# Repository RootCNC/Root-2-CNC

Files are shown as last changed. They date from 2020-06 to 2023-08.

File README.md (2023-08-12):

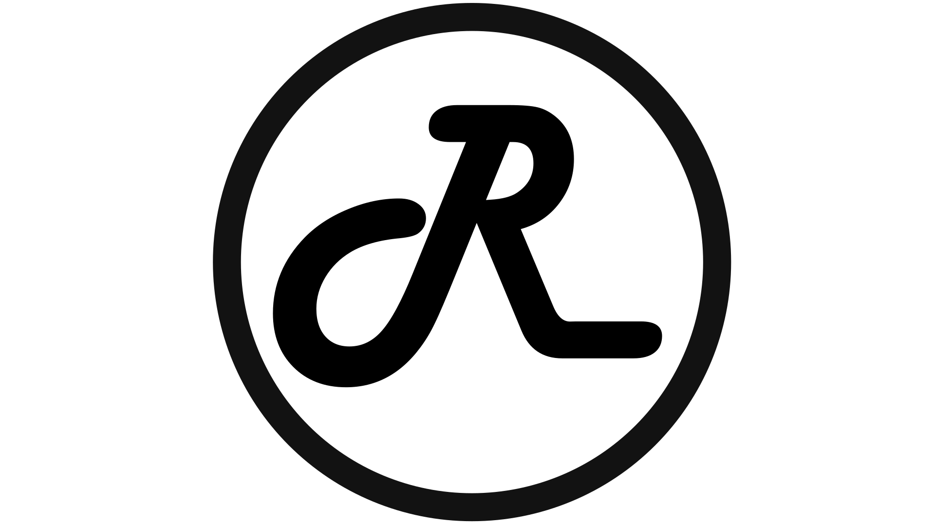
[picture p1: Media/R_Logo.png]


# Root 2 
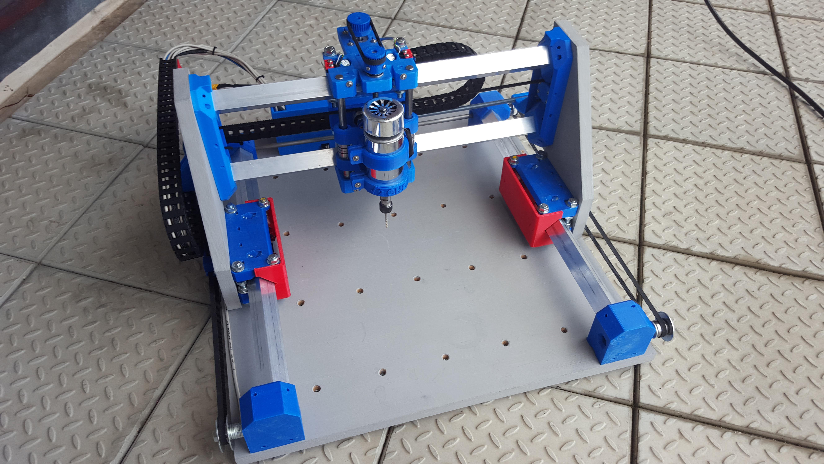
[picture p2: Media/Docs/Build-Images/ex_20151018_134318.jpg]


I started this project to enable me to do another project which required sheet wood to be machined, (another 3D printer which I have been wanting to do for a while). without the large cost of out sourcing the tasks to a company. So I created this CNC named Root 2 to open up a endless amount of possibilities.
Why make it open source? Since getting involved with 3D printing and the whole open source community, it has taught me many things and open doors which might not have been open without the added experience the community has given me. So I thought what a great way to put something small back into very thing what got me hooked in the magical world of CNC machine - the open source community.
If you make one or remix it, I would love to see it! post some photos and show it off! =]
Goals

Create a expandable CNC machine capable to machine aluminiumUse minimal different 3D printed partsCustomization (Make it Bigger)CheapSimpleUse parts commonly used in DIY 3D printerEasily sourced parts

# Goals
 1. Create a expandable CNC machine 
 2. capable to machine aluminium
 3. Use minimal different 3D printed parts 
 4. Customization (Make it Bigger)
 5. Cheap Simple 
 6. Use parts commonly used in DIY 3D printer
 7. Easily sourced parts
 
# Spec
Working Area = 331x305x120mm (X,Y,Z) - If you want a bigger machine, just buy longer box section!

# Animated Assembly 
[Here](https://www.youtube.com/watch?v=ruxc2kX1mUY&list=PL5hghy18PulU0-F_gzihovUwgWx6q6PMu&ab_channel=Sailorpete)

# BOM
Can be found [HERE](https://github.com/RootCNC/Root-2-CNC/blob/master/Docs/BOM.md)

# Videos
Youtube Videos can be found  [Here](https://www.youtube.com/sailorpete12)

Animated Assembly [Here](https://www.youtube.com/watch?v=ruxc2kX1mUY&list=PL5hghy18PulU0-F_gzihovUwgWx6q6PMu&ab_channel=Sailorpete)

## Dibond sheet
(http://www.youtube.com/watch?v=g2_bGaUY4f0 "")
## Hard Oak Sign making
(http://www.youtube.com/watch?v=TYWPhoFjMDA "")
## Aluminum
(http://www.youtube.com/watch?v=S1ygUxeEE4I "")
## Root 2 Sign
(http://www.youtube.com/watch?v=rYxTZAJLHNU "")
## Acrylic
(http://www.youtube.com/watch?v=3Kr6_sbjg4U "")
## MDF
(http://www.youtube.com/watch?v=sJx-P0i7J8o "")
## Pen Testing
(http://www.youtube.com/watch?v=YvVPL7FzFdo "")
## Movement Testing
(http://www.youtube.com/watch?v=Uq5E_fRXPA0 "")

## License

This project is licensed under the Creative Commons 4.0 license with 
Attribution-NonCommerial-ShareAlike see `LICENSE.txt` for details

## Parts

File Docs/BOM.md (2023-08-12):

---
title: Root 2 Bill of Materials
description: Root 2 Bill of Materials
published: true
date: 2022-06-28T21:37:30.411Z
tags: root 2, r2, BOM
editor: markdown
dateCreated: 2022-05-24T19:30:47.756Z
---

# Plastic Parts
|Qty | Item  |
|--|--|
|2x |Root 2 CNC - Y gantry assm-1 Y-Axis Belt Clamp GT2|
|4x |Root 2 CNC - Y gantry assm-1 Y Motion Bearing Mount|
|1x |Root 2 CNC - Y gantry assm-1 Y Drag Chain Carriage|
|1x |Root 2 CNC - Y gantry assm-1 X-Axis Carriage Y Drag Chain Mount|
|1x |Root 2 CNC - Y gantry assm-1 X-Axis Carriage Y Drag Chain Mount Idler|
|2x |Root 2 CNC - Y gantry assm-1 X-Axis Belt Clamp|
|2x |Root 2 CNC - Y gantry assm-1 X-Axis Box Bar Mount|
|2x |Root 2 CNC - Y gantry assm-1 Dirt Cover|
|1x |Root 2 CNC - X carriage-1 Z-Axis Motor Mount|
|1x |Root 2 CNC - X carriage-1 Z carriage-1 Spindle Upper Clamp|
|1x |Root 2 CNC - X carriage-1 Z carriage-1 Spindle Lower Clamp|
|1x |Root 2 CNC - X carriage-1 X-Axis Motor Mount|
|1x |Root 2 CNC - X carriage-1 X-Axis Carriage Drag Chain Mount Idler|
|2x |Root 2 CNC - X carriage-1 linear rail 90 bearing mount Y-Axis Carriage|
|1x |Root 2 CNC - X carriage-1 3M Pulley 32T 5mm|
|1x |Root 2 CNC - X carriage-1 3M Pulley 22T 8mm|
|1x |Root 2 CNC - Ramps controller-1 Ramps Case Lid|
|1x |Root 2 CNC - Ramps controller-1 Ramps Case Base|
|1x |Root 2 CNC - Base and Y axis assm-1 Y-Axis Bar Mount|
|1x |Root 2 CNC - Base and Y axis assm-1 Y-Axis Bar Mount Idler|
|1x |Root 2 CNC - Base and Y axis assm-1 Y-Axis Bar Mount Idler Mirror|
|1x |Root 2 CNC - Base and Y axis assm-1 Y-Axis Bar Mount Mirror|
|1x |Root 2 CNC - Base and Y axis assm-1 Y-Axis Motor Mount|
|1x |Root 2 CNC - Base and Y axis assm-1 Y-Axis Motor Mount Mirror|
|1x |Root 2 CNC - Base and Y axis assm-1 Y-Axis Drag Chain|
|1x |Root 2 CNC - Base and Y axis assm-1 3M Pulley 48T 8mm|
|1x |Root 2 CNC - Base and Y axis assm-1 3M Pulley 24T 5mm|
|4x |Root 2 CNC - Base and Y axis assm- Foot|
# Electronics
|Qty | Item  |
|--|--|
|1x| Arduino Mega + Ramps 1.4|
|3x| DRV8825 (Optional but preferred over the A4988)|
|3x| Nema 17 Stepper motors (Get the Highest torque possible)|
|1x| 60mm DC Fan|
|6x| Endstop micro switches (KW11 I drilled the whole to 3mm to screw then in to the plastic parts)|
|1x| DC Spindle (52mm Diameter - Get the highest wattage, you will be thank full later on)|
|1x| Diode This is needed if using the heatbed Mosfet on the ramps to control the spindle - google Mosfet switching inductive loads for more information|
|4| core AWG26 cable (use for motor wiring and endstops)|
# Fixings
|Qty | Item  |
|--|--|
|4x|M8 Penny washers|
|Lots|M8 Standard washers|
|lots|M8 Nuts|
|24x| M8 x 25mm Bolts|
|2x |M8 x 35-40mm Bolt|
|16x| M8 Tee Nuts|
|2x |M4 x 50mm Bolt|
|16x| M4 Nuts|
|16x| M4 Washer|
|16x| M4 x 40mm Bolt|
|Lots |M3 9mm Penny Washers|
|Lots |M3 Nuts|
|10x |M3 x 10mm|
|lots |M3 x 16,20,25,30,40 mm Lengths (good to have a selection on hand)
# Bearings
|Qty | Item  |
|--|--|
|36x| 608 Bearings|
|4x| LM10UU|
# Metal Work
|Qty | Item  |
|--|--|
|2x|Aluminum Box section (X-Axis) 25x25x496x3mm (W,D,L,T)|
|2x|Aluminum Box section (Y-Axis) 25x25x496x3mm (W,D,L,T)|
|1x|M8 Smooth Rod 580mm|
|8x|M8 Threaded Rod 85 mm|
|1x|M8 Threaded Rod 500 mm|
|2x|M8 Threaded Rod 200 mm|
|1x|M8 Threaded Rod 230 mm|
|2x|M8 Threaded Rod 100 mm|
|2x|M10 Smooth Rod 185 mm
# Motion
|Qty | Item  |
|--|--|
||GT2 Belt (Length depending on size of the of the machine)|
|2x|GT2 36T Pulley 8mm Bore|
|1x|3M-210T-06 Belt|
|1x|3M-264T-06 HTD|
|1x|GT2 16T Pulley 5mm Bore|
|2x|Drag Chain 20 x 10 mm 1m Length|
# Wood
|Qty | Item  |
|--|--|
|2x|Wood Side Panel|
|1x|Wood Base|

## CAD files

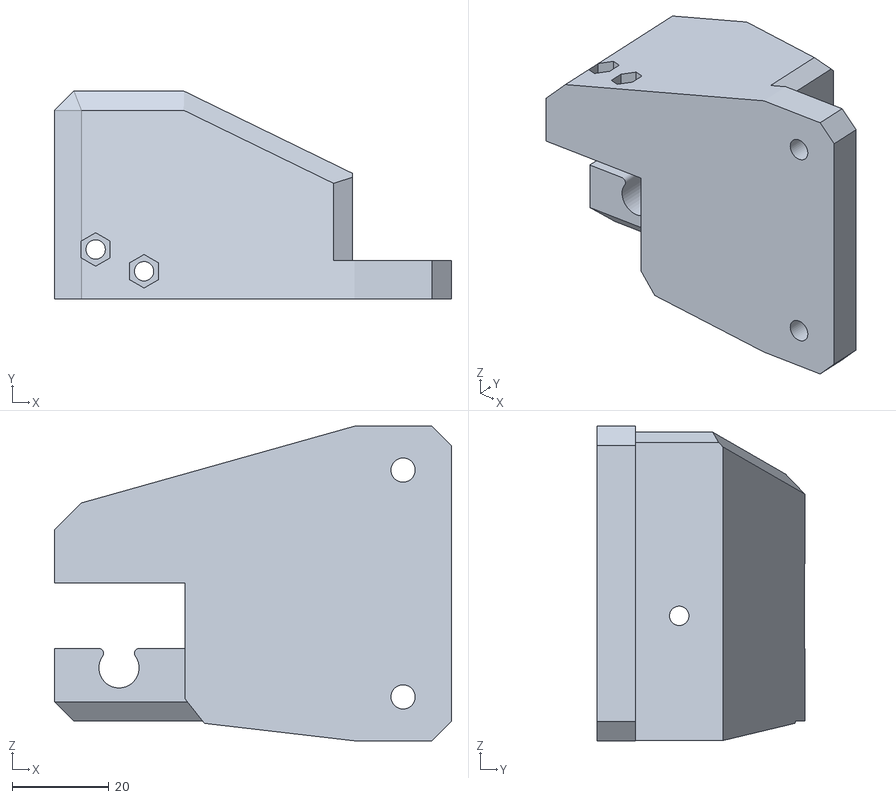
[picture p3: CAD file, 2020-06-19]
STL_Files/Drag Chain/X-Axis/Root 2 CNC - Y gantry assm-1 X-Axis Carriage Y Drag Chain Mount.STL
82.0 x 43.0 x 65.0

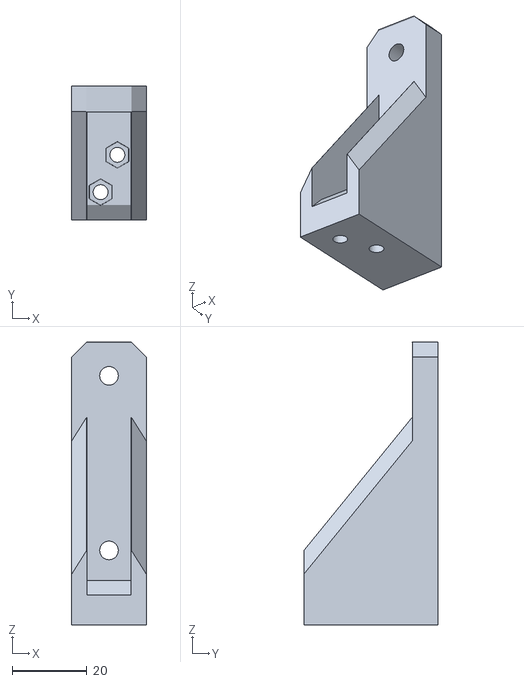
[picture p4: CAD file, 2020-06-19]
STL_Files/Drag Chain/Y-Axis/Y Drag Chain Carriage.STL
20.0 x 36.0 x 75.9

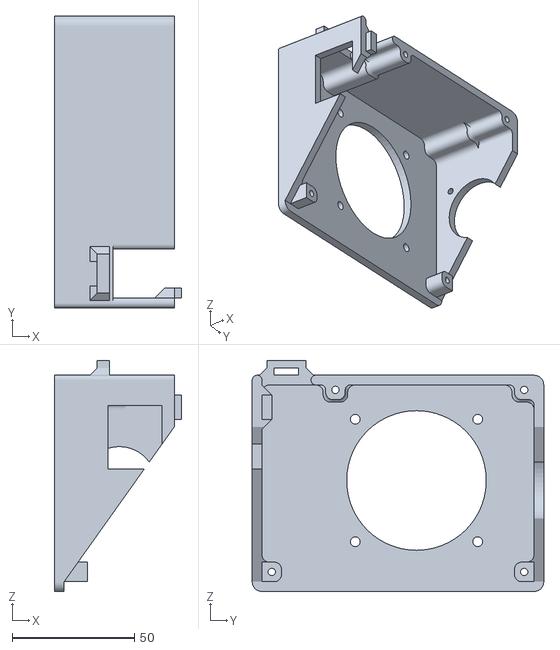
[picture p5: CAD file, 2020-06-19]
STL_Files/Electronics Case/Root 2 CNC - Ramps controller-1 Ramps Case Lid.STL
52.0 x 119.1 x 94.3

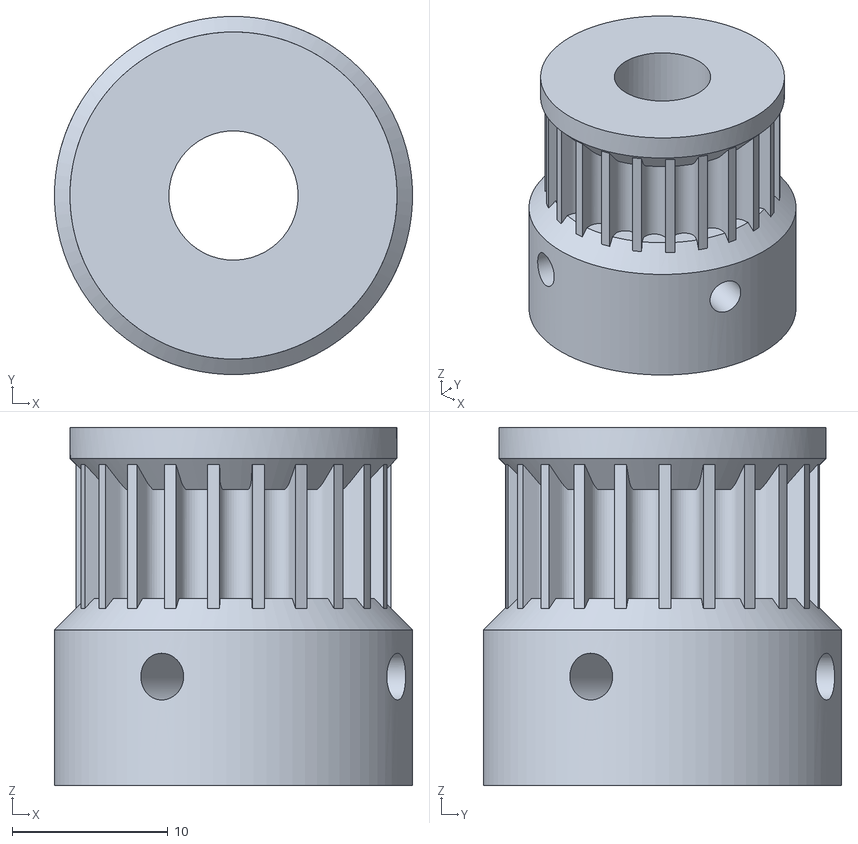
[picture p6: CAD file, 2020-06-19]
STL_Files/X Carriage/Root 2 CNC - X carriage-1 3M Pulley 22T 8mm.STL
23.0 x 23.0 x 23.0

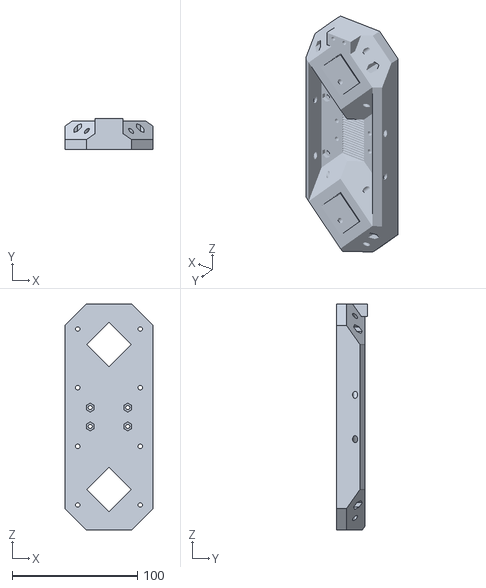
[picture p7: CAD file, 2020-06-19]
STL_Files/Y Gantry/X-Axis Box Bar Mount (METRIC 25mm).STL
70.0 x 25.0 x 180.6

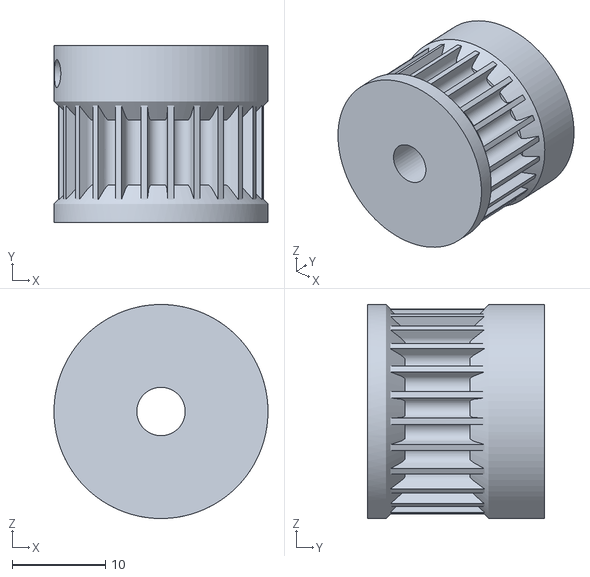
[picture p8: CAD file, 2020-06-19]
STL_Files/Y Motion/3M Pulley 24T 5mm.STL
23.0 x 19.0 x 23.0

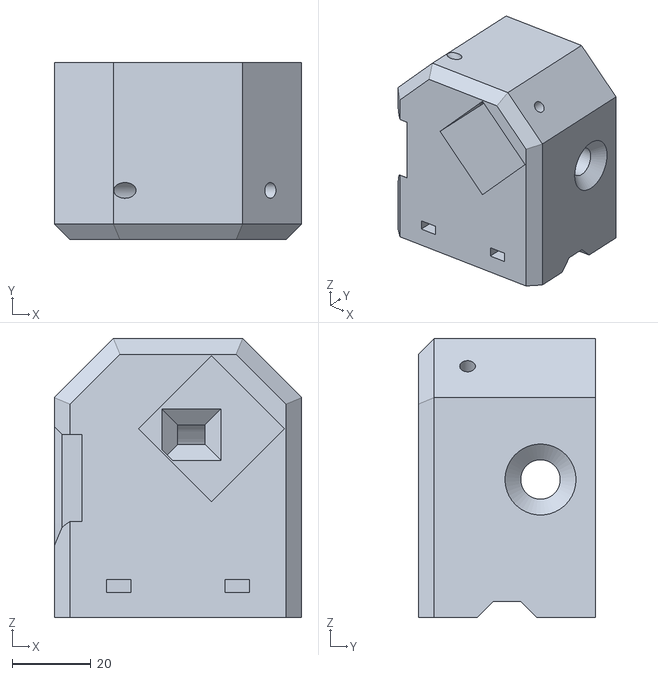
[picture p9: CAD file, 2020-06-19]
STL_Files/Y Motion/INCHES 1'/Root 2 CNC - Base and Y axis assm-1 Y-Axis Bar Mount INCHES.STL
62.8 x 45.0 x 70.8

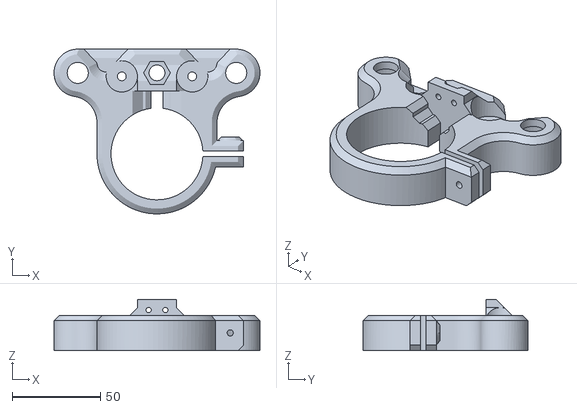
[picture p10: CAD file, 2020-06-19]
STL_Files/Z Carraige/52mm/Spindle Clamp 52mm Bottom.STL
117.0 x 93.6 x 29.0

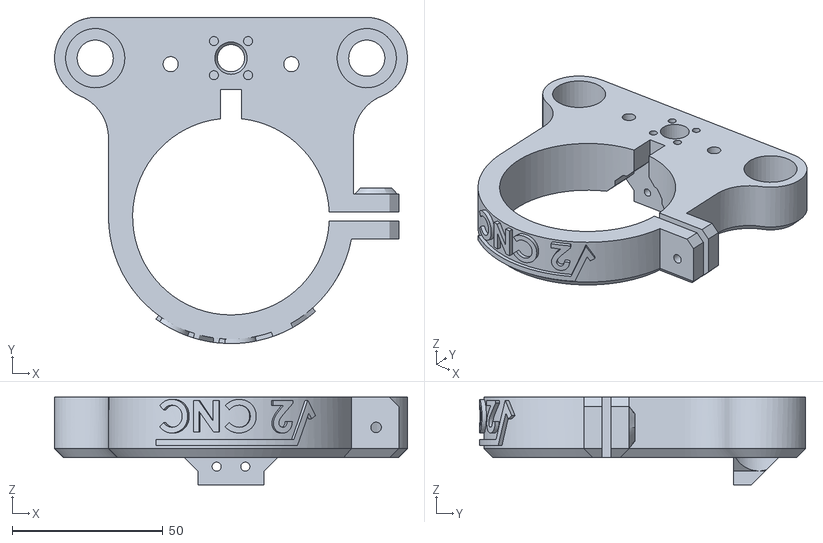
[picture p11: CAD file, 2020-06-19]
STL_Files/Z Carraige/65mm/Spindle Clamp 65mm Top.STL
117.0 x 108.1 x 29.0

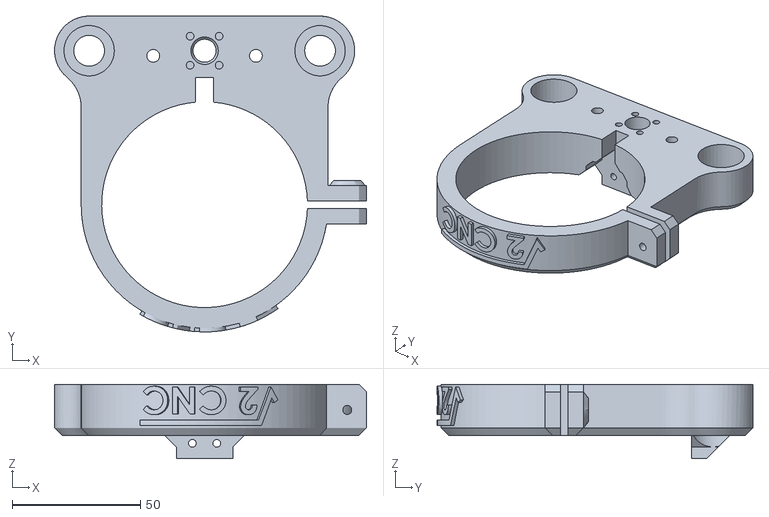
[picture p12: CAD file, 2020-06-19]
STL_Files/Z Carraige/80mm/Spindle Clamp 80mm Top.STL
121.6 x 123.1 x 29.0

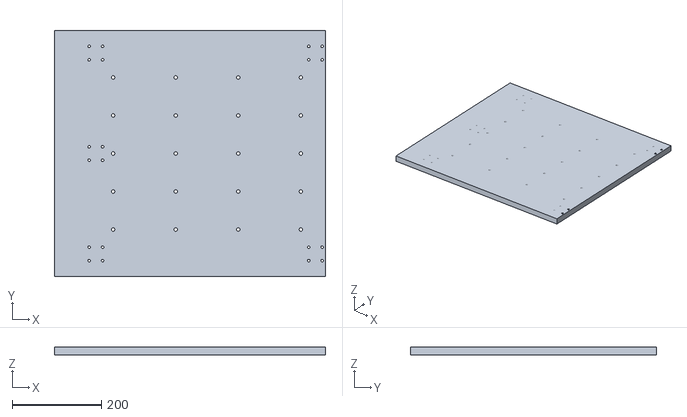
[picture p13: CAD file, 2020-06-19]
Wooden_Parts/Base Board.STL
606.0 x 550.0 x 18.0

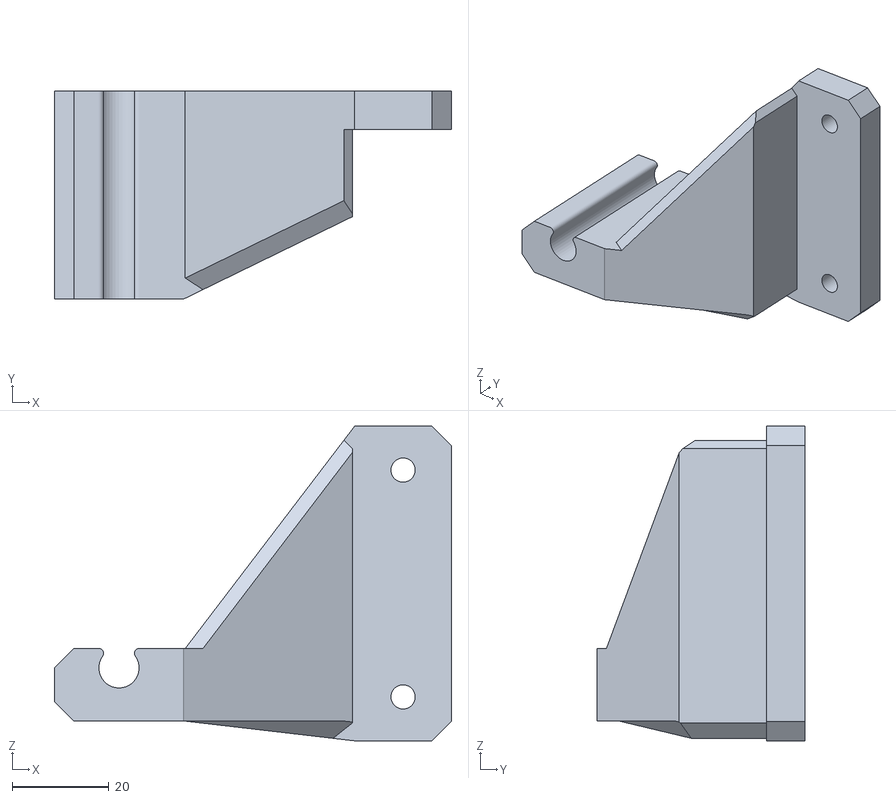
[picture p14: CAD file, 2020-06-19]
STL_Files/Drag Chain/X-Axis/X-Axis Carriage Y Drag Chain Mount Idler.STL
82.0 x 43.0 x 65.0

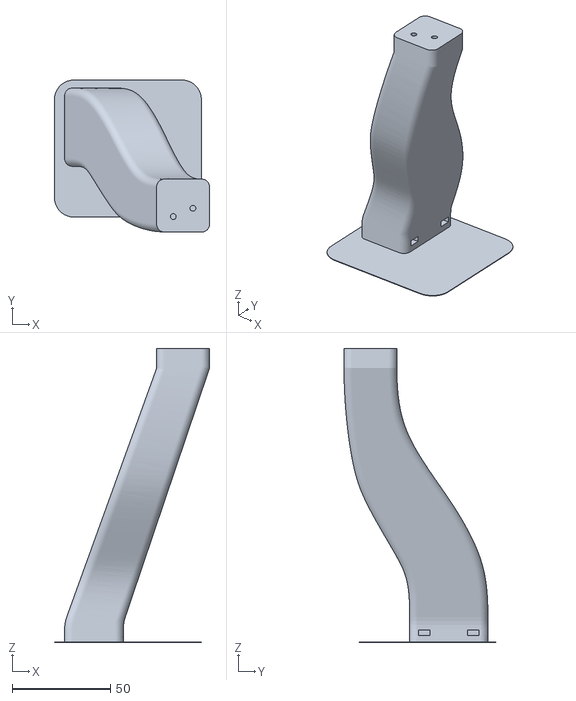
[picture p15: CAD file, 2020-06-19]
STL_Files/Drag Chain/Y-Axis/Y-Axis Drag Chain.STL
79.2 x 77.6 x 150.0

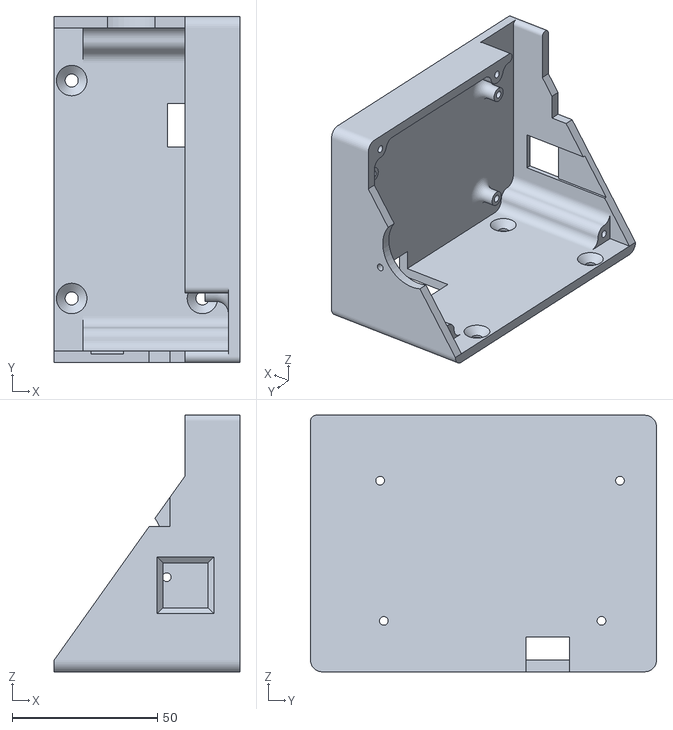
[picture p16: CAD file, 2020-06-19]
STL_Files/Electronics Case/Root 2 CNC - Ramps controller-1 Ramps Case Base.STL
64.0 x 119.1 x 88.3

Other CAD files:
STL_Files/Y Motion/METRIC 25mm/Y-Axis Bar Mount.STL
STL_Files/Z Carraige/66.4mm/Spindle Clamp 66.4mm Top.STL
STL_Files/X Carriage/X-Axis Motor Mount.STL
STL_Files/Y Gantry/X-Axis Belt Clamp.STL
STL_Files/X Carriage/3M Pulley 32T 5mm.STL
STL_Files/X Carriage/X-Axis Carriage Drag Chain Mount Idler.STL
STL_Files/X Carriage/Z-Axis Motor Mount.STL
STL_Files/X Carriage/linear rail 90 bearing mount Y-Axis Carriage.STL
STL_Files/Y Gantry/Dirt Cover.STL
STL_Files/Y Gantry/X-Axis Box Bar Mount (INCHES 1'').STL
STL_Files/Y Gantry/X-Axis Side Pannel (Wood).STL
STL_Files/Y Gantry/Y Motion Bearing Mount.STL
STL_Files/Y Gantry/Y-Axis Belt Clamp GT2.STL
STL_Files/Y Motion/3M Pulley 48T 8mm.STL
STL_Files/Y Motion/Foot.STL
STL_Files/Y Motion/INCHES 1'/Root 2 CNC - Base and Y axis assm-1 Y-Axis Bar Mount Idler INCHES.STL
STL_Files/Y Motion/METRIC 25mm/Y-Axis Bar Mount Idler Mirror.STL
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

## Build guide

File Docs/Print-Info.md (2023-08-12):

---
title: Root 2 Print Orientation
description: How to print the parts for the Root 2
published: true
date: 2022-06-28T22:24:57.245Z
tags: root 2, how to print
editor: markdown
dateCreated: 2022-06-28T22:17:17.168Z
---

# How to Print
Print settings for any of the Root CNC machine is key for a long lasting - high performance CNC machine. Below are the setting I used:

Resolution: 0.25-0.35mm
Infill: 50-60%
## Notes:
- Strength is key! use the hardest settings possible
- Print with 3-4 perimeters
- Print with ABS, PETG PLA will be fine though your mileage may vary (I am worried about the low glass transistion point of PLA being too low for the motors)
# Base and Y axis assm- Foot
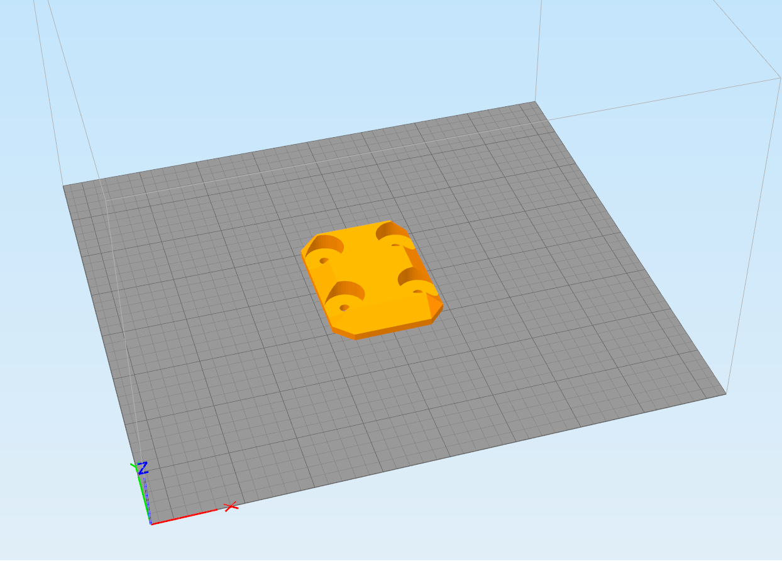
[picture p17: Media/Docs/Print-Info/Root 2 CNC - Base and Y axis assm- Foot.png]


# Base and Y axis assm-1 Y-Axis Bar Mount Idler
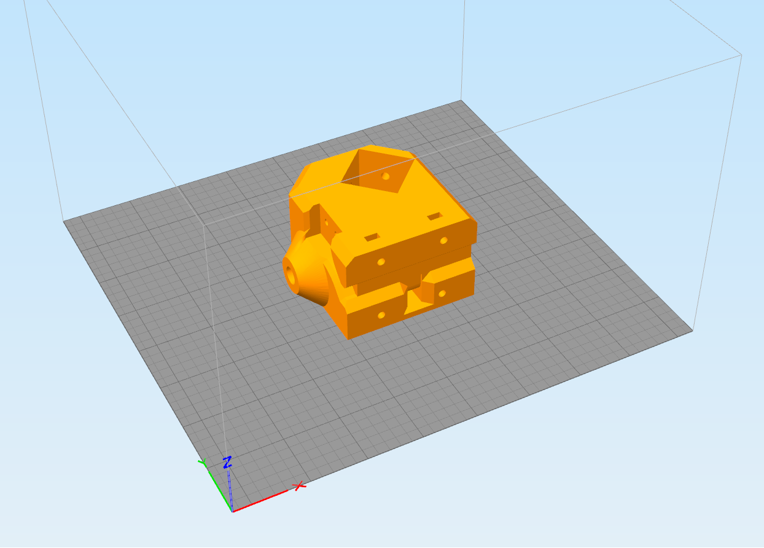
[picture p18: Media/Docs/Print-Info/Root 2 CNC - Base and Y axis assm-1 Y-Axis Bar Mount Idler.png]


# Base and Y axis assm-1 Y-Axis Bar Mount
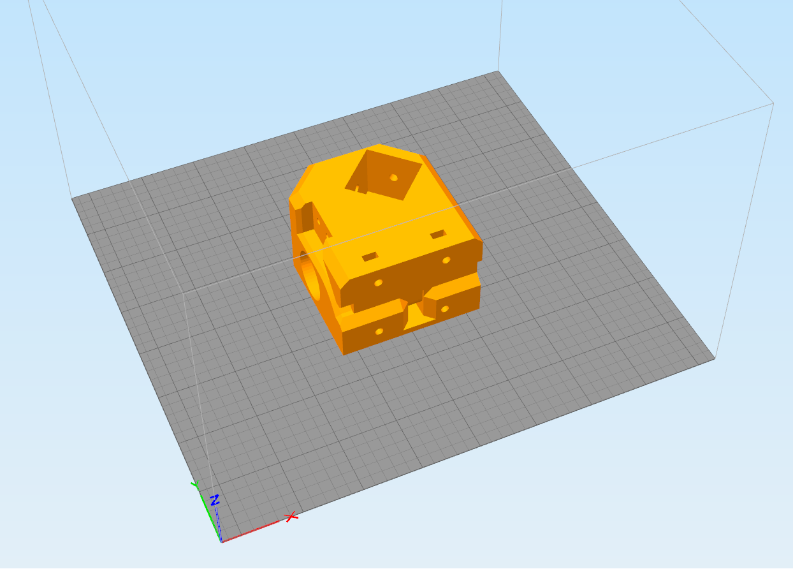
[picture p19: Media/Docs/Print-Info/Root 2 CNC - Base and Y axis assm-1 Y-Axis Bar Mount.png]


# Base and Y axis assm-1 Y-Axis Drag Chain
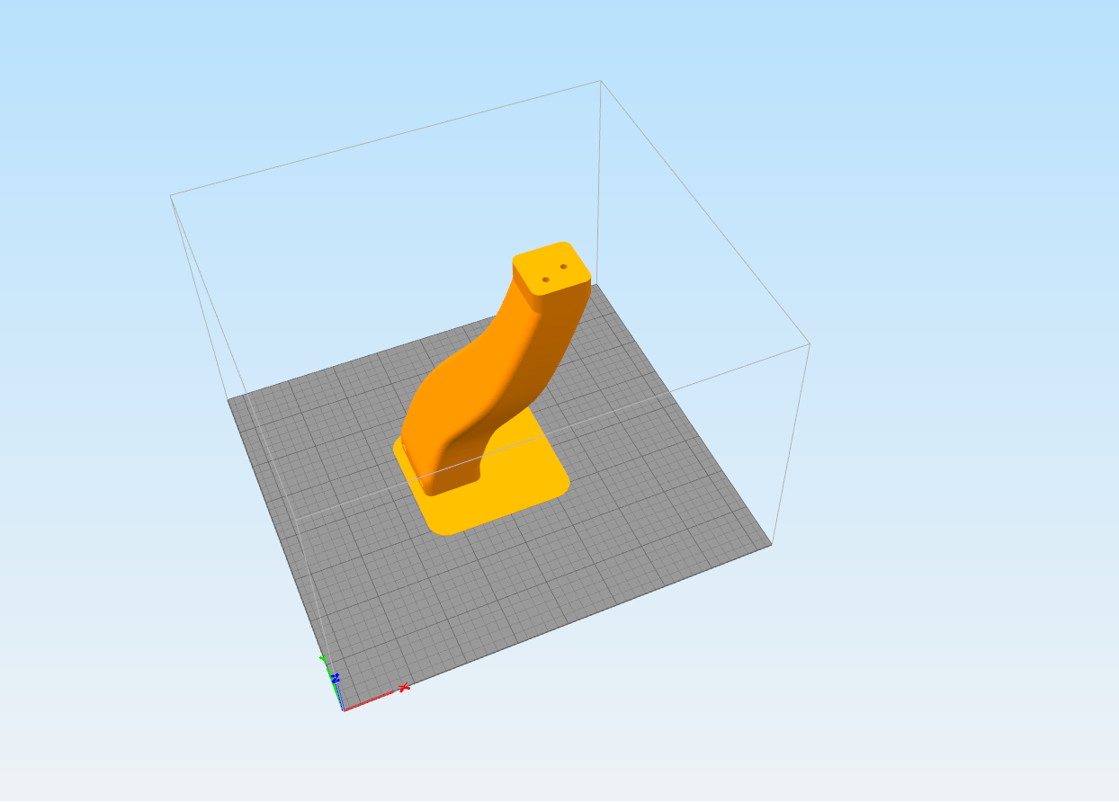
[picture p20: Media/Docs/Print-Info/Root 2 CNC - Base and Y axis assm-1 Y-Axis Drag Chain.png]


# Base and Y axis assm-1 Y-Axis Motor Mount
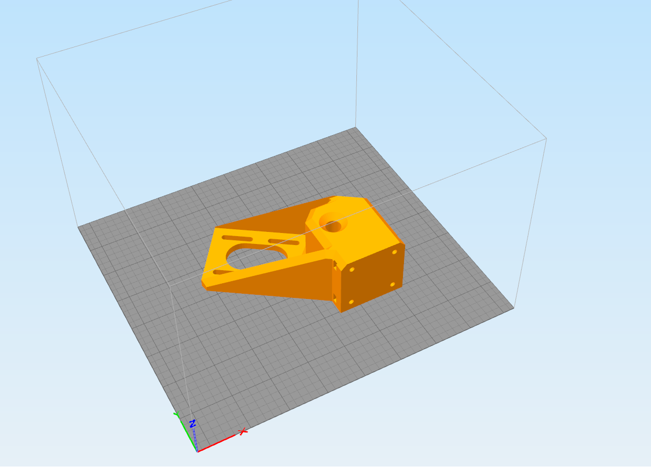
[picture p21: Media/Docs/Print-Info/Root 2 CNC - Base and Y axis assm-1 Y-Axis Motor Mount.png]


# Ramps controller-1 Ramps Case Base
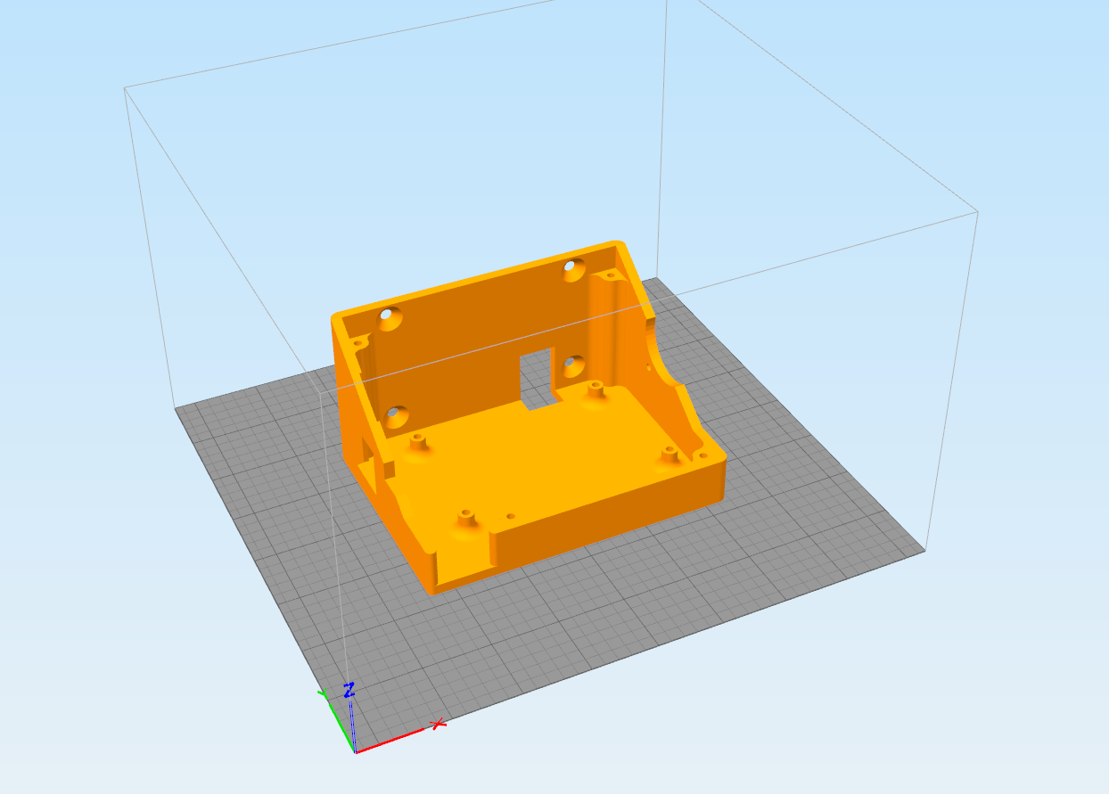
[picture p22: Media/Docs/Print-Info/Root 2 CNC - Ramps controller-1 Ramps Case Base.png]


# Ramps controller-1 Ramps Case Lid
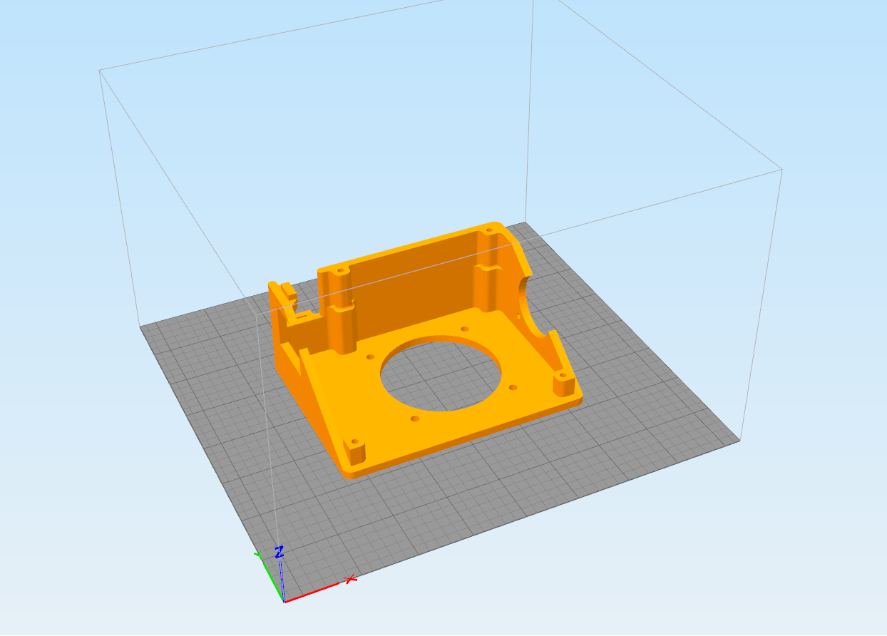
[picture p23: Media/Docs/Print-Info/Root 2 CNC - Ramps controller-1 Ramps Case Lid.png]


# X carriage-1 linear rail 90 bearing mount Y-Axis Carriage
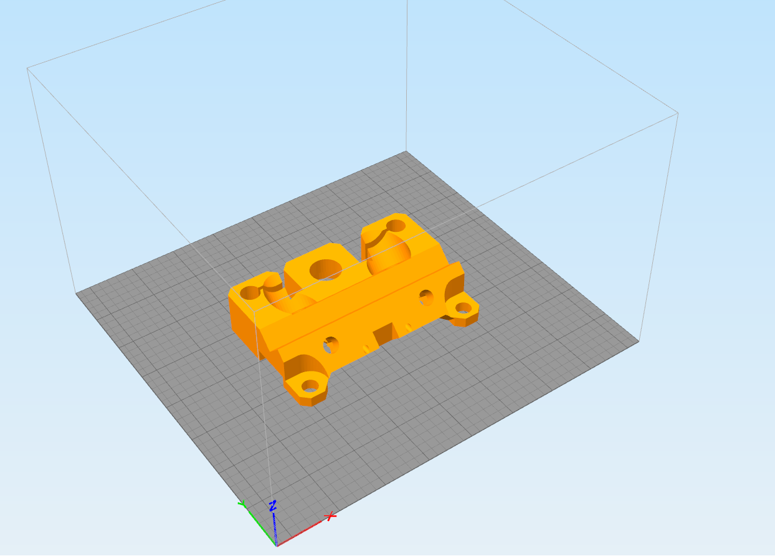
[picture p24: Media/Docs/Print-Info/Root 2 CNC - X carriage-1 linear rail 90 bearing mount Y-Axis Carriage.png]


# X carriage-1 X-Axis Carriage Drag Chain Mount Idler
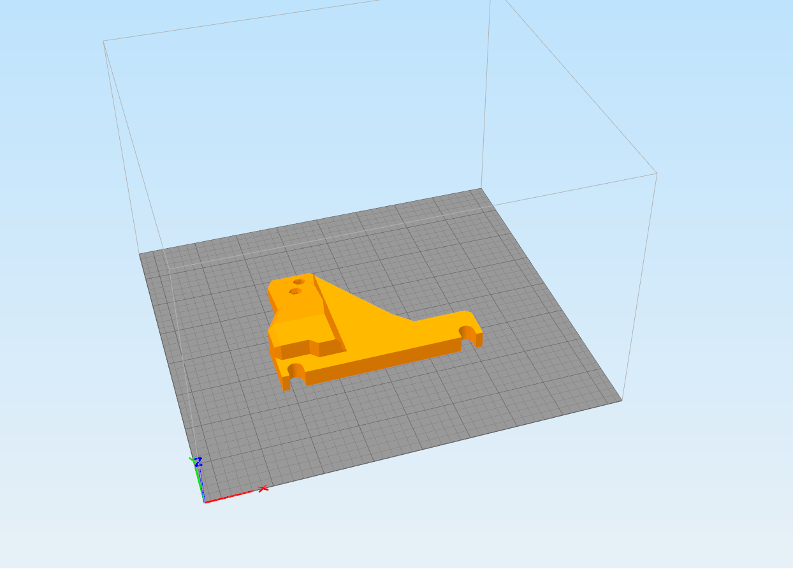
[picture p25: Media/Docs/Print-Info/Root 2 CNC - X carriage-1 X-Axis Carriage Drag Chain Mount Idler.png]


# X carriage-1 X-Axis Motor Mount
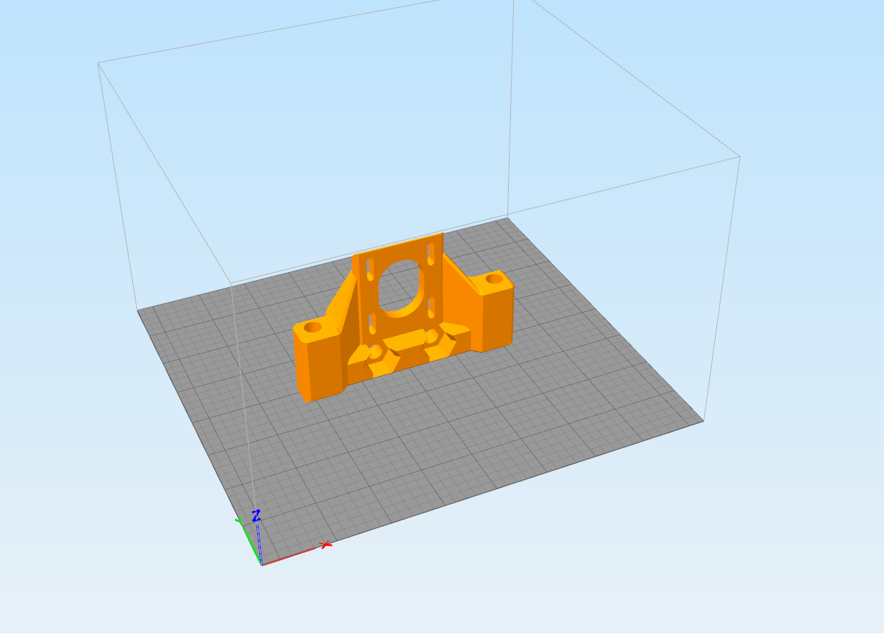
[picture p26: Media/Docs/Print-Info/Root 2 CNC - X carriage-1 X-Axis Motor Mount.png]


# X carriage-1 Z carriage-1 Spindle Lower Clamp
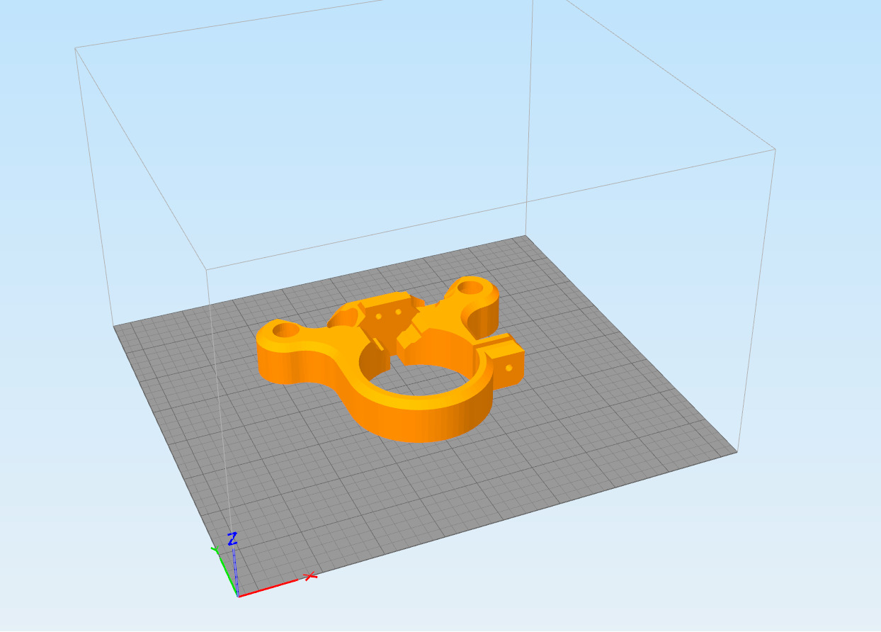
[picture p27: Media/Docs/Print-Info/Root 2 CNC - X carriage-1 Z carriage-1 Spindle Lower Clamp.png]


# X carriage-1 Z carriage-1 Spindle Upper Clamp
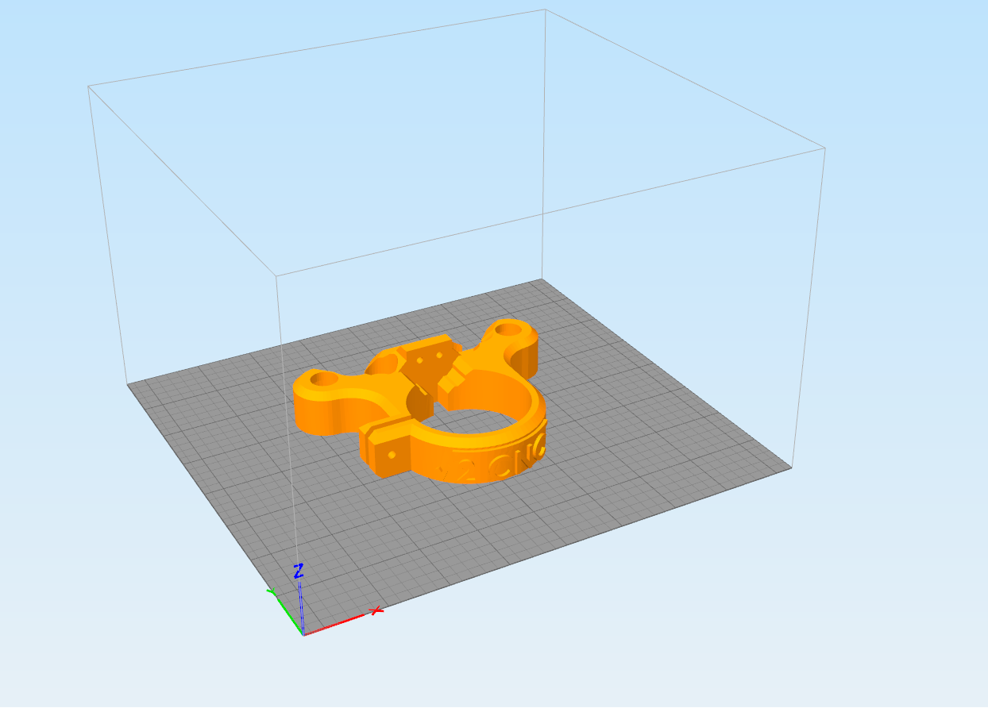
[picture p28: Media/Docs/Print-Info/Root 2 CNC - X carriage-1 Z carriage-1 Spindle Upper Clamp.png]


# X carriage-1 Z-Axis Motor Mount
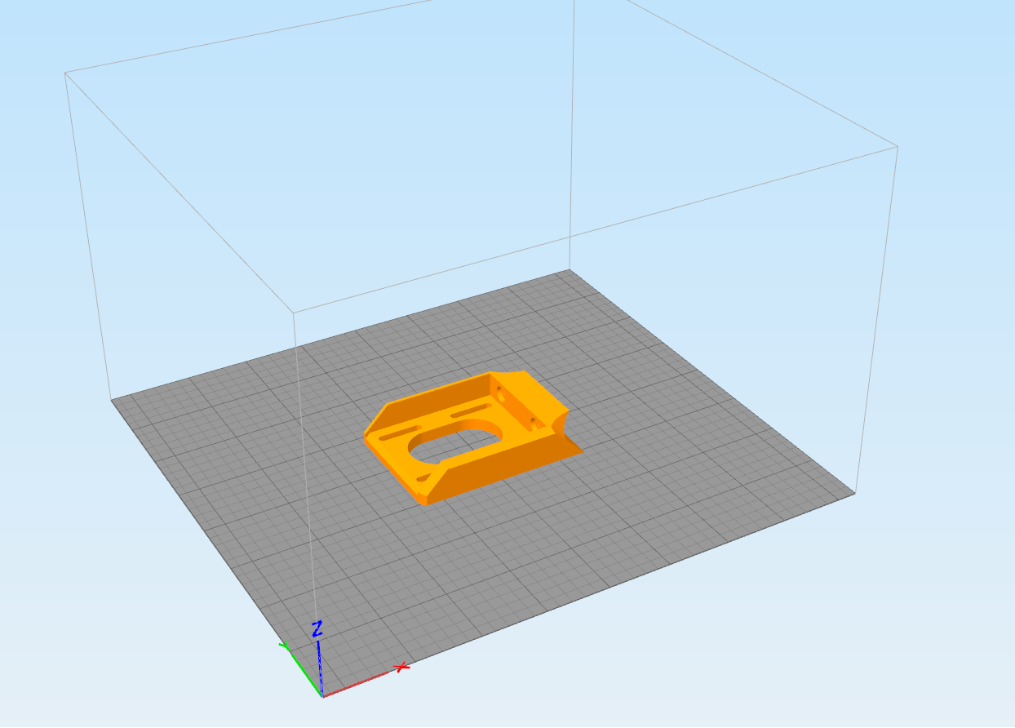
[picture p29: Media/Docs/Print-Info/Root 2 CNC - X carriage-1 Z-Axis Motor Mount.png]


# Y gantry assm-1 Dirt Cover
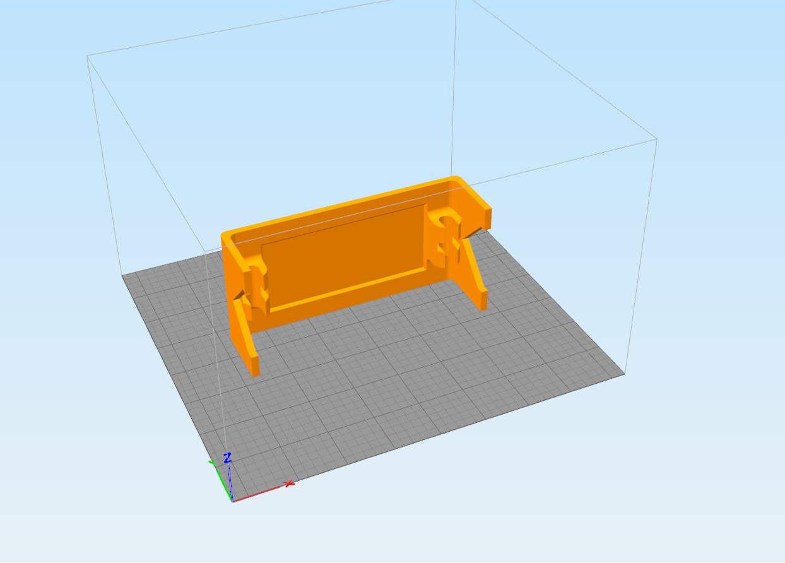
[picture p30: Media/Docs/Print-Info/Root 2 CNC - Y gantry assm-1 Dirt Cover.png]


# Y gantry assm-1 X-Axis Belt Clamp
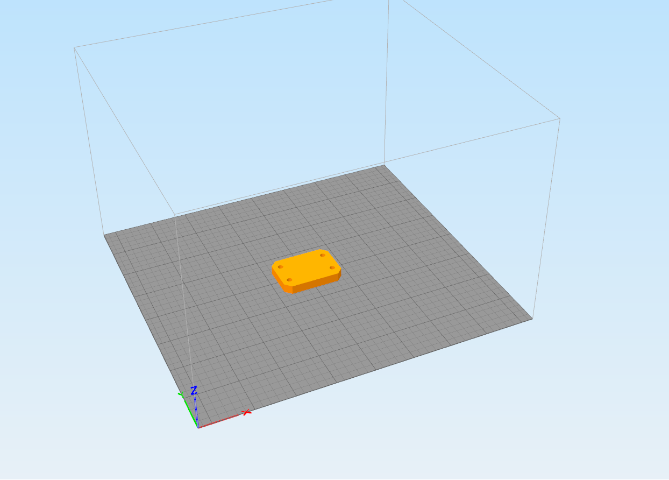
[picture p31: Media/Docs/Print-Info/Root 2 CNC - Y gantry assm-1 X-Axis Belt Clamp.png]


# Y gantry assm-1 X-Axis Box Bar Mount
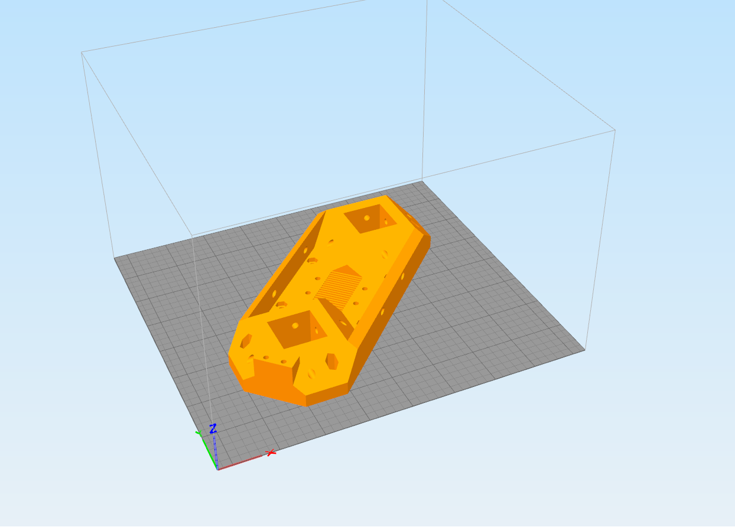
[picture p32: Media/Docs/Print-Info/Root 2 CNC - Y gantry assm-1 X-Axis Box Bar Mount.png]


# Y gantry assm-1 X-Axis Carriage Y Drag Chain Mount
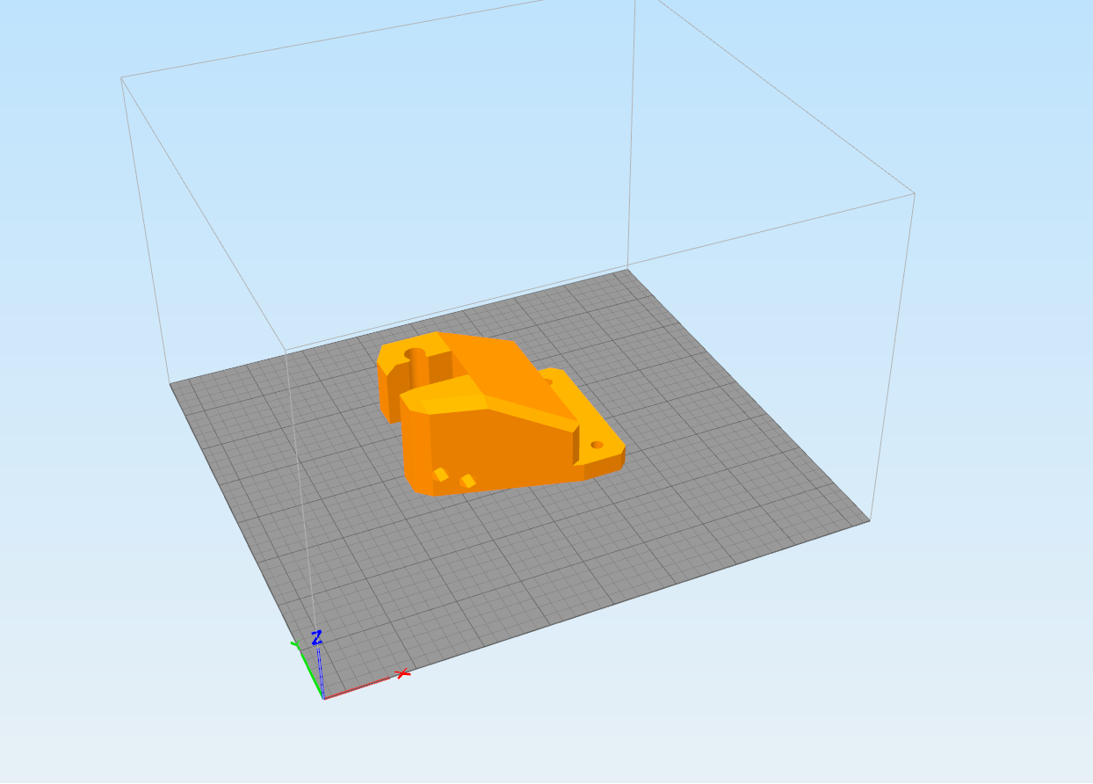
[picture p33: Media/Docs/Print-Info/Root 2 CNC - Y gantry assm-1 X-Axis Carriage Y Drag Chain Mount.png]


# Y gantry assm-1 Y Drag Chain Carriage
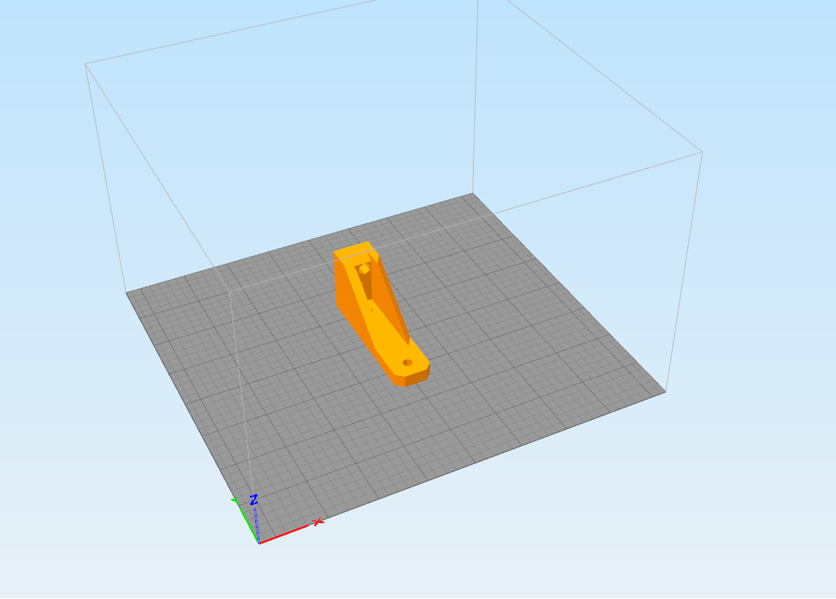
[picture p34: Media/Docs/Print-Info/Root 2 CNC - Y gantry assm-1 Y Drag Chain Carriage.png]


# Y gantry assm-1 Y Motion Bearing Mount
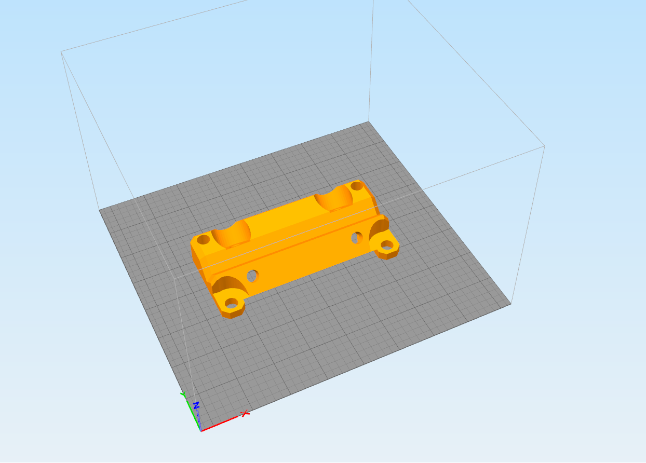
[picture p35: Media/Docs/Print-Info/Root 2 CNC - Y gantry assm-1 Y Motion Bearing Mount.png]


# Y gantry assm-1 Y-Axis Belt Clamp GT2
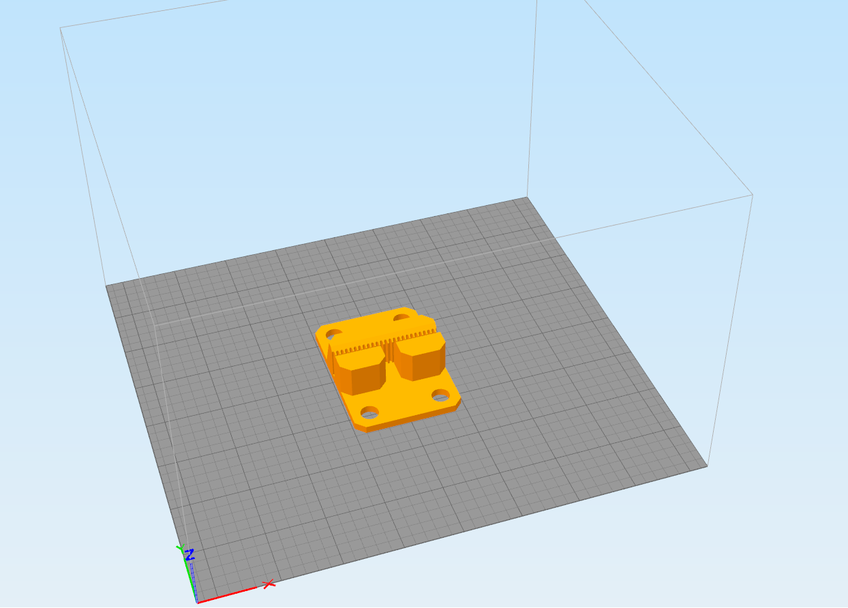
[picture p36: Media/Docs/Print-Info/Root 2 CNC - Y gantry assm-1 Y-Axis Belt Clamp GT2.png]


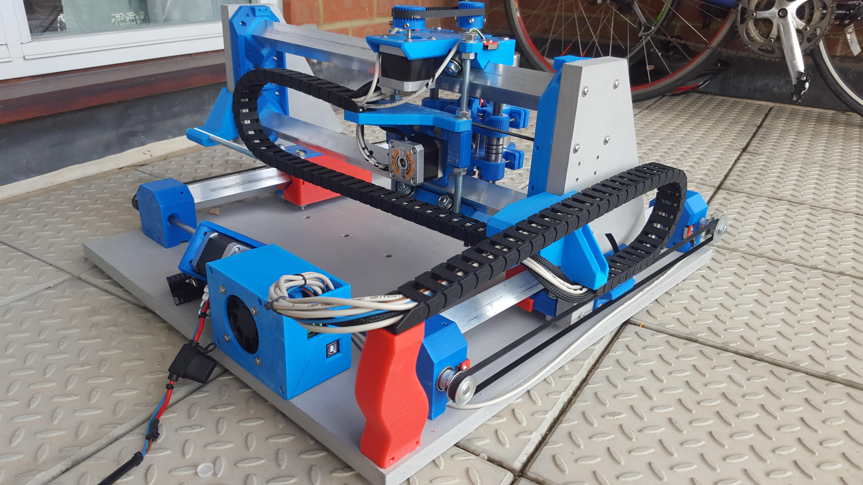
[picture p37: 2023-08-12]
Media/Docs/Build-Images/ex_20151018_134442.jpg

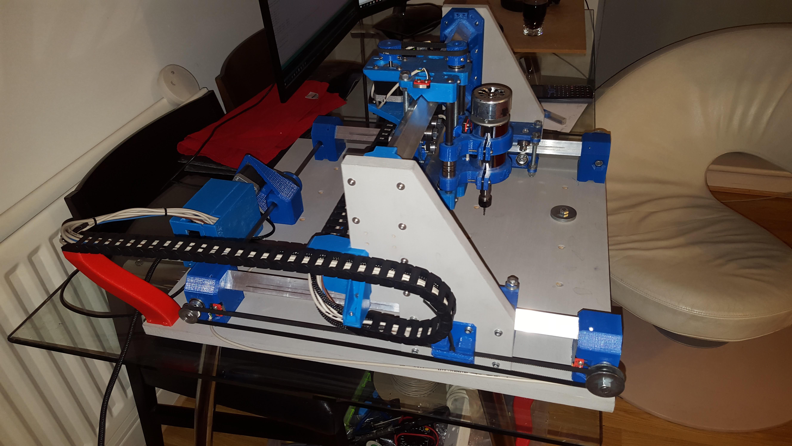
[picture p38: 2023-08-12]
Media/Docs/Build-Images/ex_20151009_202629.jpg

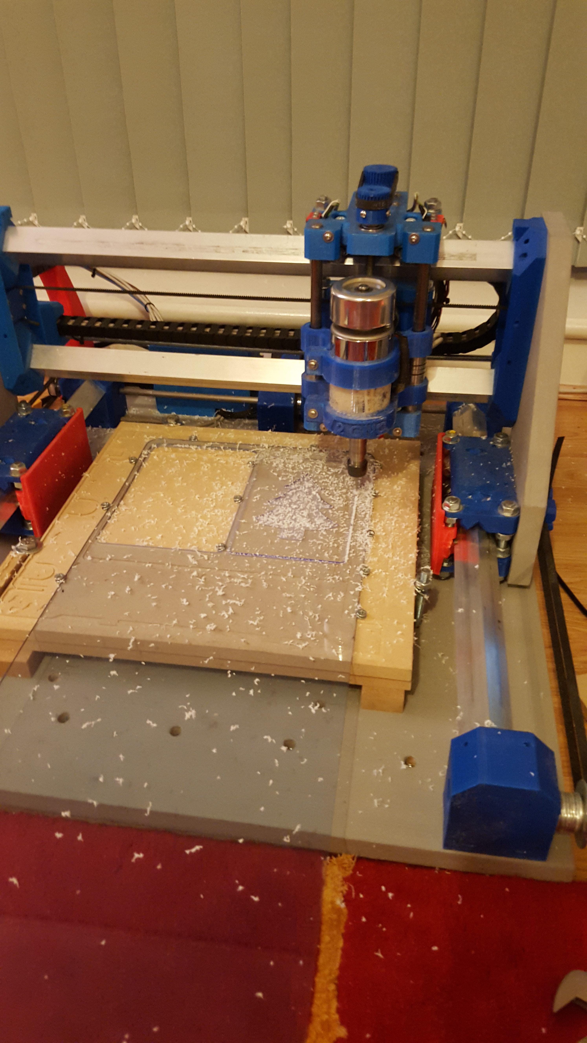
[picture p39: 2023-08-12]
Media/Docs/Build-Images/ex_20151202_203619-e1496259471879.jpg

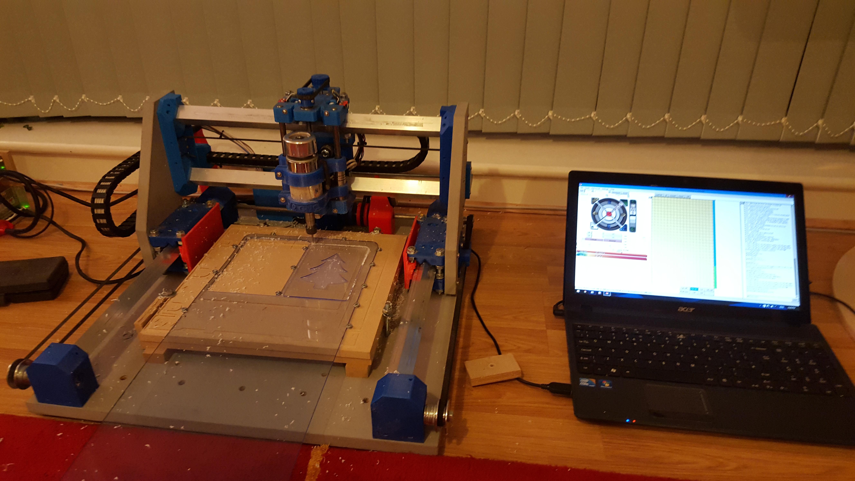
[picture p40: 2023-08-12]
Media/Docs/Build-Images/ex_20151202_203641.jpg

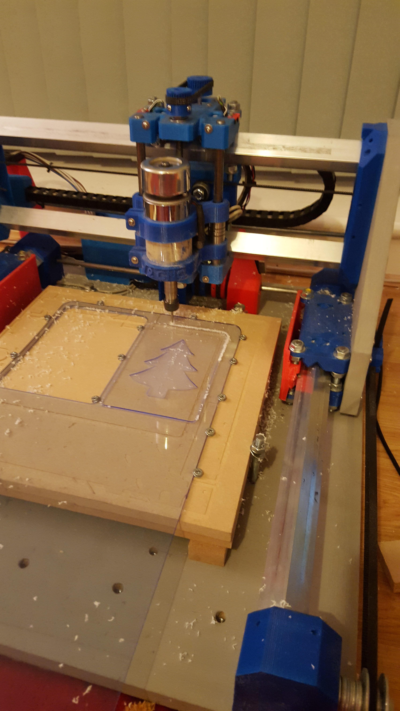
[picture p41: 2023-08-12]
Media/Docs/Build-Images/ex_20151202_203637-e1496259277843.jpg

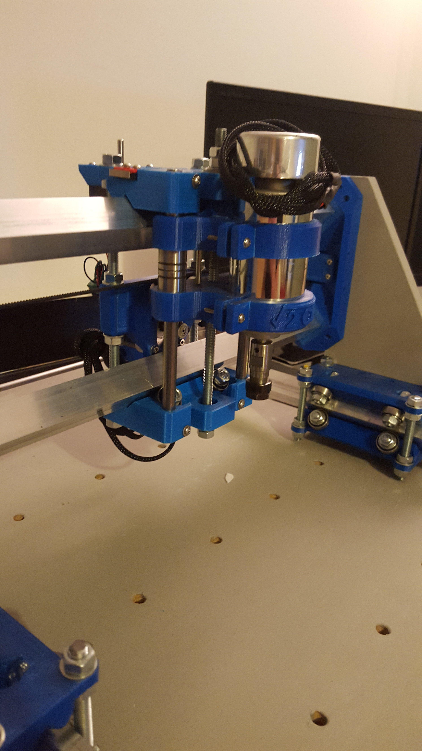
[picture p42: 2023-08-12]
Media/Docs/Build-Images/ex_20150905_211445-e1496258416164.jpg

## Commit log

2020-06-19 First_upload
    First Commit for the Root 2 CNC Project - More information to come
    [3M Pulley 24T 5mm.STL, 3M Pulley 32T 5mm.STL, 3M Pulley 48T 8mm.STL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]
2023-08-12 Added print information
2023-08-12 Added BOM
